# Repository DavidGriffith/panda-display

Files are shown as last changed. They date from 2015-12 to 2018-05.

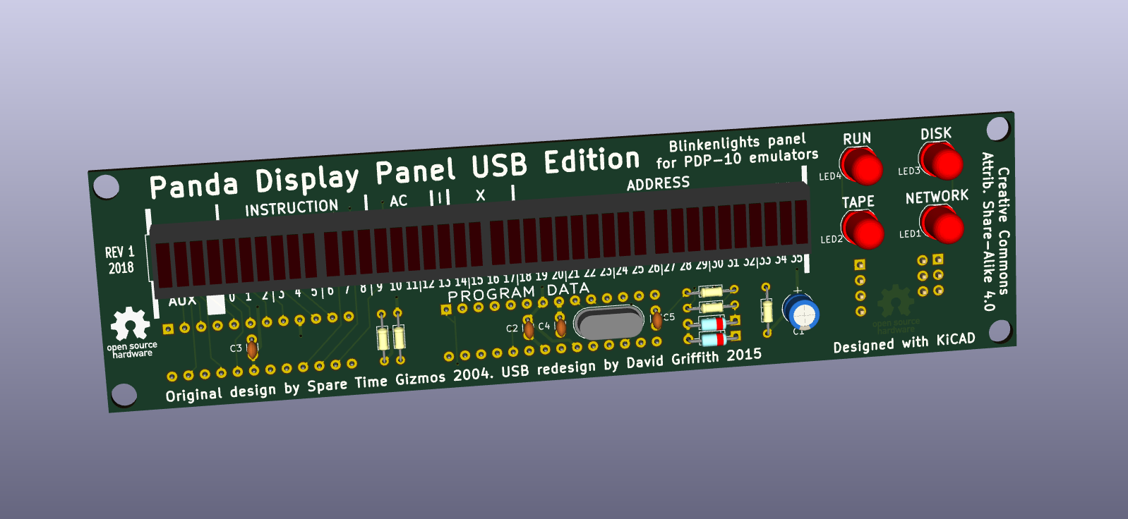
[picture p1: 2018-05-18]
panda-front.png

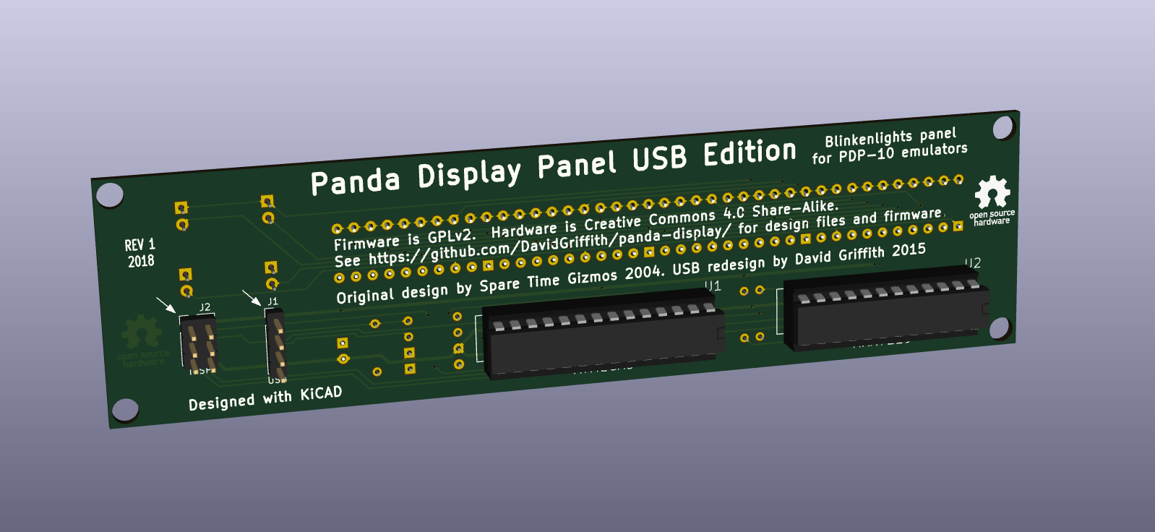
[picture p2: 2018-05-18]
panda-back.png

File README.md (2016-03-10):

Panda Display Panel
===================

---

The Panda Display Panel is a hardware peripheral for use with the klh10 
pdp-10 emulator.  It was originally presented by Spare Time Gizmos.  
This one replaces the parallel port interface with a USB interface.

The original Panda Display Panel page is at 
http://www.sparetimegizmos.com/Hardware/Panda.htm

**Bill of Materials**

|Connectors| |
|:---|---|
|J1| 1 x 4 0.1" header strip|
|J2| 2 x 3 0.1" header strip|
|U1| 28-pin narrow DIP socket|
|U2| 24-pin narrow DIP socket|

|Semiconductors| |
|:---|---|
|U1|		ATmega8 microcontroller -- 28-pin narrow DIP|
|U2|		Maxim MAX7219 matrix digit display driver -- 24-pin narrow DIP|
|D1,D2|		1N747 3.6V zener diodes|
|BAR1-BAR4|	10 segment LED bar display -- Lite-On LTA-1000HR|
|LED1-LED4|	Standard brightness red LED 5mm -- Kingbright WP1503ID|

|Crystals| |
|:---|---|
|Y1|		16MHz quartz crystal -- HC49/US low profile|

|Resistors| |
|:---|---|
|R1|		2.2K 0.25W 5%|
|R2|		4.7K 0.25W 5%|
|R3,R4|		68 0.25W 5%|
|R5|		10K  0.25W 5%|

|Capacitors| |
|:---|---|
|C1|		10uF 25V electrolytic or tantalum|
|C2,C3|		0.1uF ceramic monolithic|
|C4,C5|		22pF ceramic monolithic|

**Assembly Notes**

Pay careful attention to the fact that the chips are mounted on the rear 
of the board and most of the passives are on the front.

1.  Mount the passive components first.  Make sure the leads are trimmed 
    so they won't interfere with the chip sockets.  The polarized 
    capacitor should be laid down on its side.
2.  Wash flux residue off the rear.  The chip sockets will make this 
    more difficult later.
3.  Mount the chip sockets and the header strips on the rear
4.  Mount the LED bars and the discrete LEDs on the front.

The discrete LEDs may be pressed up against the board unless you decide 
to mount the LED bars in sockets.  If you want to do that, first mount 
sockets and install the LED bars in the sockets.  Then insert a discrete 
LED and turn the Panda Display over such that the LED bars lie flat upon 
the table.  Let the discrete LED fall against the table.  Once you're 
satisfied that the discrete LED is level with the LED bars, solder the 
discrete LED in place.  Repeat for the other discrete LEDs.

To build and install the firmware, you must have the AVR-GCC development 
environment including compiler, binutilities, and libc 
(http://www.nongnu.org/avr-libc/) and AVRDUDE
(http://www.nongnu.org/avrdude/) installed.  Most if not all current 
distributions of Linux and BSD include packages for installing these.  
You will also need an AVR programming device supported by AVRDUDE.  A 
USBtinyISP (https://www.adafruit.com/products/46) is commonly-available, 
reliable, and inexpensive.

It's a good idea to add your programmer to your system's udev rules.  
For the USBtinyISP, see https://learn.adafruit.com/usbtinyisp/avrdude

**Mounting and Use**

The Panda Display is intended to be mounted in a 5.25" external drive 
bay behind a knockout panel.  It's up to you to make this as simply or 
elaborately as you desire.  An overlay may be applied over the top to 
dress it up.

This edition of the Panda Display is powered and driven through a USB 
port.  There are two ways of going about the cabling.  If you have a 
spare USB header on your computer's motherboard, you'll need to make up 
a four-conductor cable terminated at both ends with a 1x4 0.1" female 
header socket.

If you have a regular Type-A socket inside your computer, take an 
ordinary USB cable, cut off the Type-B end, trim the jacket, and crimp 
the conductors to a 1x4 0.1" female header socket.

Finally, to make any meaningful use of the Panda Display, you will need 
a PDP-10 emulator which has been patched to make use of it.  Since 
Kenneth L. Harrenstien's klh10 pdp-10 emulator was patched by Mark 
Crispin to use the original Panda Display, I chose to modify that to use 
this new Panda Display.  Get it here: 
https://github.com/DavidGriffith/klh10.

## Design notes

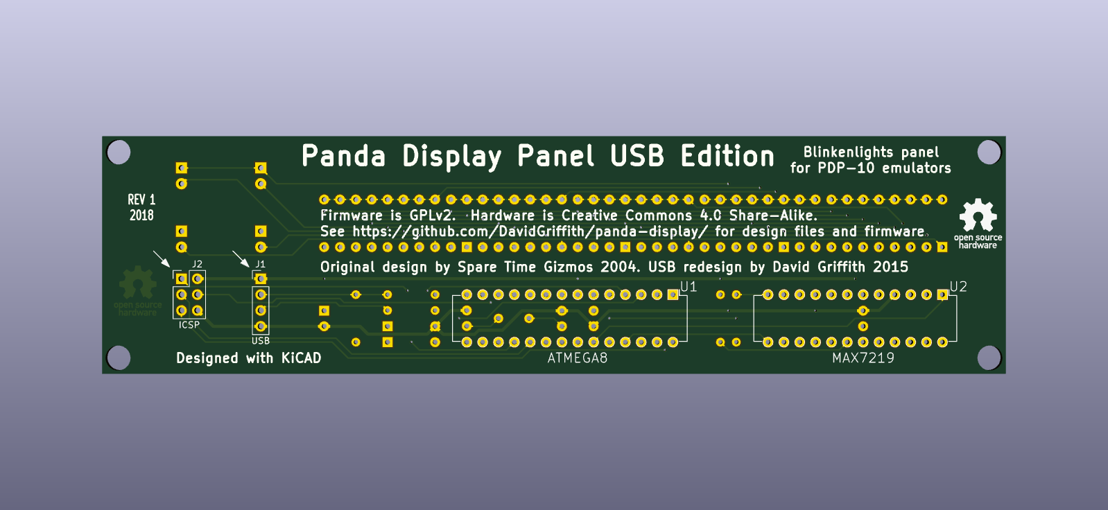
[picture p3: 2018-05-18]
panda-back-bare.png

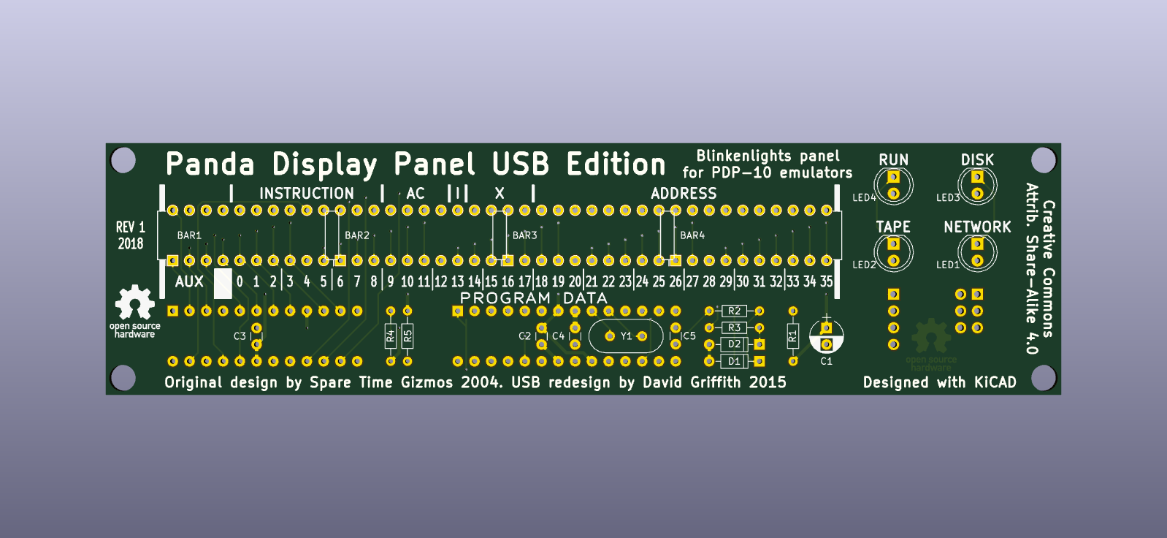
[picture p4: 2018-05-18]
panda-front-bare.png

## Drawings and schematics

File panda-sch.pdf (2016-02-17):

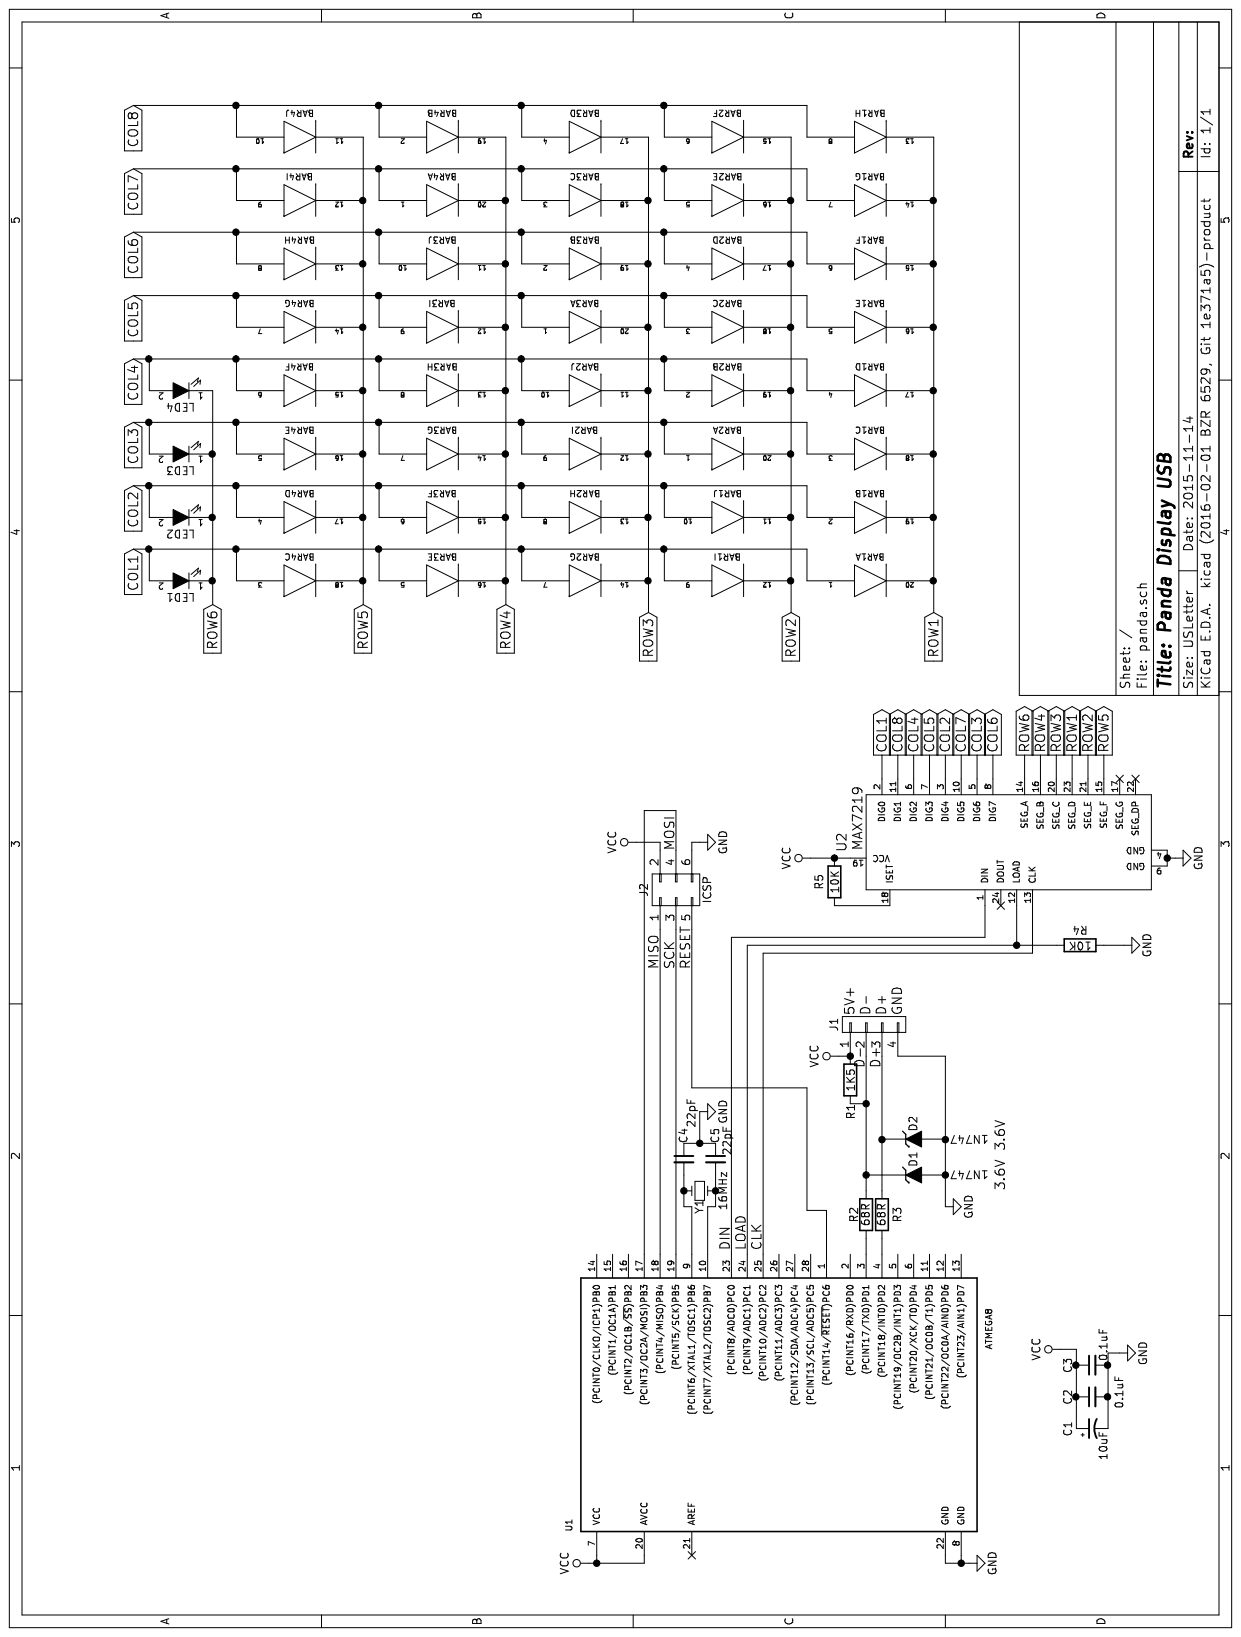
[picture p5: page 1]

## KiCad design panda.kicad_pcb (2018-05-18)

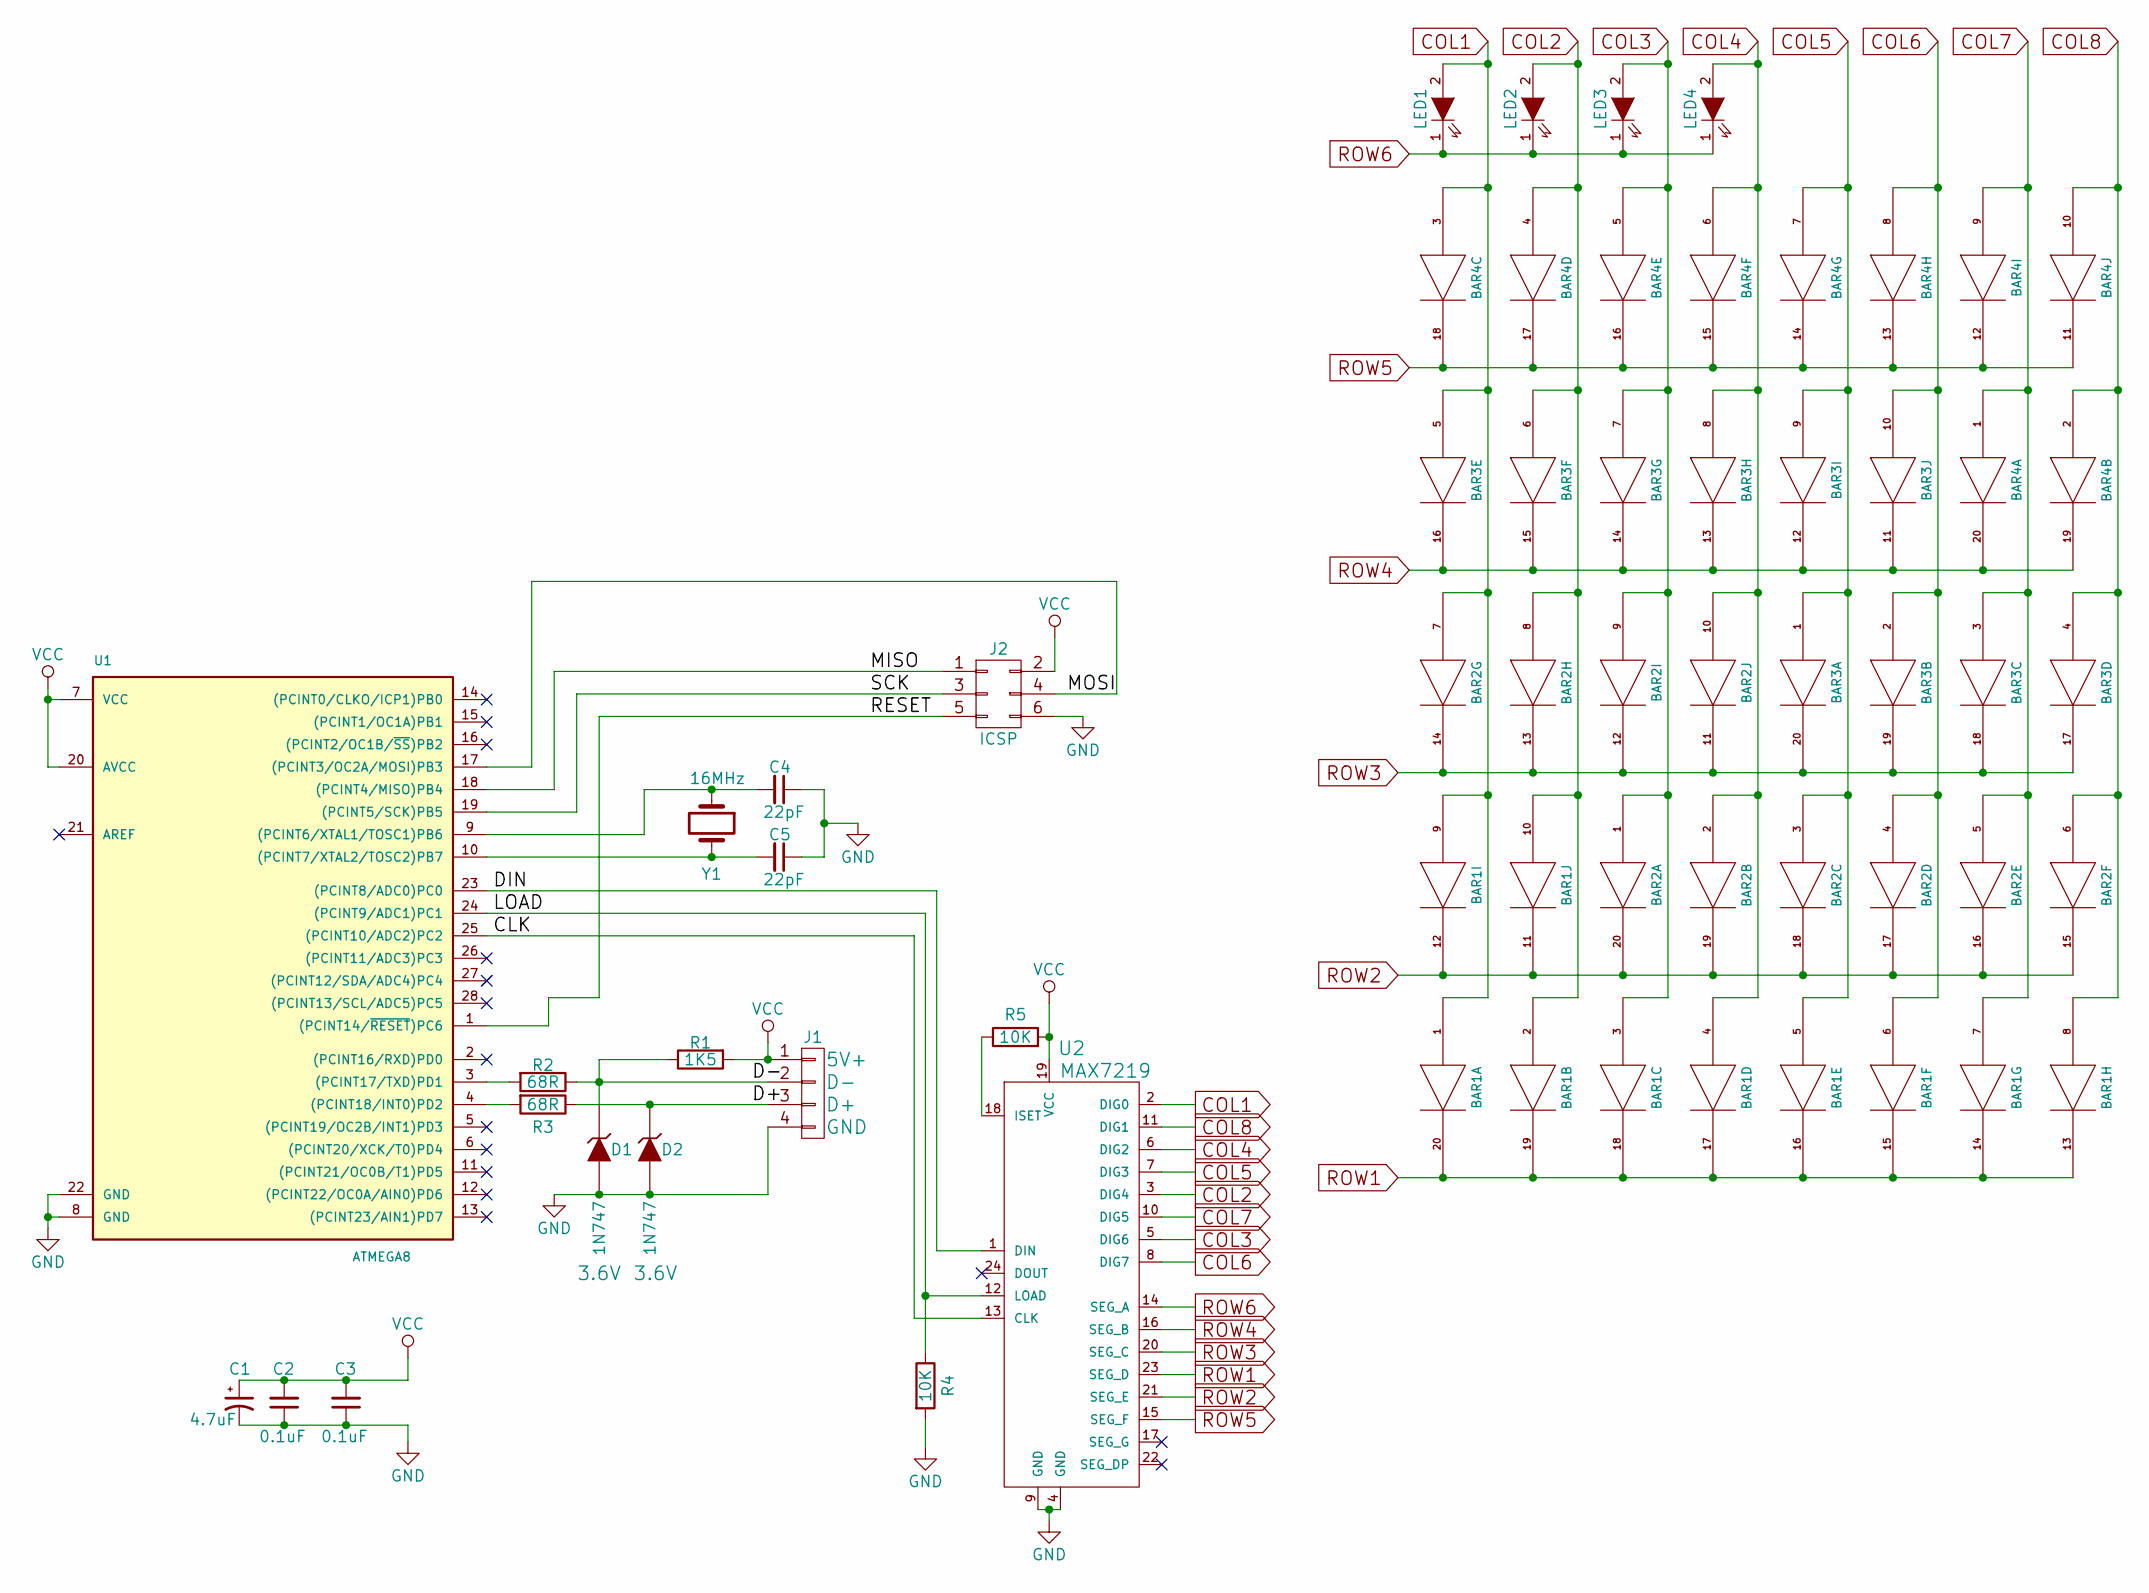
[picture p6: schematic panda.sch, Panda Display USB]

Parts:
BAR1, BAR2, BAR3, BAR4: DOT-BAR; DIP-20_W7.62mm
C1: 4.7uF; CP_Radial_D5.0mm_P2.50mm
C2, C3: 0.1uF; C_Disc_D3.0mm_W1.6mm_P2.50mm
C4, C5: 22pF; C_Disc_D3.0mm_W1.6mm_P2.50mm
D1, D2: 1N747; D_DO-35_SOD27_P7.62mm_Horizontal; Voltage 3.6V
J1: USB; Pin_Header_Straight_1x04_Pitch2.54mm
J2: ICSP; Pin_Header_Straight_2x03_Pitch2.54mm
LED1, LED2, LED3, LED4: LED; LED_D5.0mm
R1: 1K5; R_Axial_DIN0204_L3.6mm_D1.6mm_P7.62mm_Horizontal
R2, R3: 68R; R_Axial_DIN0204_L3.6mm_D1.6mm_P7.62mm_Horizontal
R4, R5: 10K; R_Axial_DIN0204_L3.6mm_D1.6mm_P7.62mm_Horizontal
U1: ATMEGA8; DIP-28_W7.62mm
U2: MAX7219; DIP-24_W7.62mm
Y1: 16MHz; Crystal_HC49-U_Vertical

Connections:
/CLK: U1.25 ((PCINT10/ADC2)PC2), U2.13 (CLK)
/D+: D2.1 (K), J1.3, R3.1
/D-: D1.1 (K), J1.2, R1.1, R2.1
/DIN: U1.23 ((PCINT8/ADC0)PC0), U2.1 (DIN)
/LOAD: R4.1, U1.24 ((PCINT9/ADC1)PC1), U2.12 (LOAD)
/MISO: J2.1, U1.18 ((PCINT4/MISO)PB4)
/MOSI: J2.4, U1.17 ((PCINT3/OC2A/MOSI)PB3)
/RESET: J2.5, U1.1 ((PCINT14/~RESET~)PC6)
/SCK: J2.3, U1.19 ((PCINT5/SCK)PB5)
COL1: BAR1.1 (A), BAR1.9 (A), BAR2.7 (A), BAR3.5 (A), BAR4.3 (A), LED1.2 (A), U2.2 (DIG0)
COL2: BAR1.2 (A), BAR1.10 (A), BAR2.8 (A), BAR3.6 (A), BAR4.4 (A), LED2.2 (A), U2.3 (DIG4)
COL3: BAR1.3 (A), BAR2.1 (A), BAR2.9 (A), BAR3.7 (A), BAR4.5 (A), LED3.2 (A), U2.5 (DIG6)
COL4: BAR1.4 (A), BAR2.2 (A), BAR2.10 (A), BAR3.8 (A), BAR4.6 (A), LED4.2 (A), U2.6 (DIG2)
COL5: BAR1.5 (A), BAR2.3 (A), BAR3.1 (A), BAR3.9 (A), BAR4.7 (A), U2.7 (DIG3)
COL6: BAR1.6 (A), BAR2.4 (A), BAR3.2 (A), BAR3.10 (A), BAR4.8 (A), U2.8 (DIG7)
COL7: BAR1.7 (A), BAR2.5 (A), BAR3.3 (A), BAR4.1 (A), BAR4.9 (A), U2.10 (DIG5)
COL8: BAR1.8 (A), BAR2.6 (A), BAR3.4 (A), BAR4.2 (A), BAR4.10 (A), U2.11 (DIG1)
GND: C1.2, C2.1, C3.1, C4.1, C5.1, D1.2 (A), D2.2 (A), J1.4, J2.6, R4.2, U1.8 (GND), U1.22 (GND), U2.4 (GND), U2.9 (GND)
unnamed: C4.2, U1.9 ((PCINT6/XTAL1/TOSC1)PB6), Y1.1
unnamed: C5.2, U1.10 ((PCINT7/XTAL2/TOSC2)PB7), Y1.2
unnamed: R2.2, U1.3 ((PCINT17/TXD)PD1)
unnamed: R3.2, U1.4 ((PCINT18/INT0)PD2)
unnamed: R5.1, U2.18 (ISET)
ROW1: BAR1.13 (K), BAR1.14 (K), BAR1.15 (K), BAR1.16 (K), BAR1.17 (K), BAR1.18 (K), BAR1.19 (K), BAR1.20 (K), U2.23 (SEG_D)
ROW2: BAR1.11 (K), BAR1.12 (K), BAR2.15 (K), BAR2.16 (K), BAR2.17 (K), BAR2.18 (K), BAR2.19 (K), BAR2.20 (K), U2.21 (SEG_E)
ROW3: BAR2.11 (K), BAR2.12 (K), BAR2.13 (K), BAR2.14 (K), BAR3.17 (K), BAR3.18 (K), BAR3.19 (K), BAR3.20 (K), U2.20 (SEG_C)
ROW4: BAR3.11 (K), BAR3.12 (K), BAR3.13 (K), BAR3.14 (K), BAR3.15 (K), BAR3.16 (K), BAR4.19 (K), BAR4.20 (K), U2.16 (SEG_B)
ROW5: BAR4.11 (K), BAR4.12 (K), BAR4.13 (K), BAR4.14 (K), BAR4.15 (K), BAR4.16 (K), BAR4.17 (K), BAR4.18 (K), U2.15 (SEG_F)
ROW6: LED1.1 (K), LED2.1 (K), LED3.1 (K), LED4.1 (K), U2.14 (SEG_A)
VCC: C1.1, C2.2, C3.2, J1.1, J2.2, R1.2, R5.2, U1.7 (VCC), U1.20 (AVCC), U2.19 (VCC)

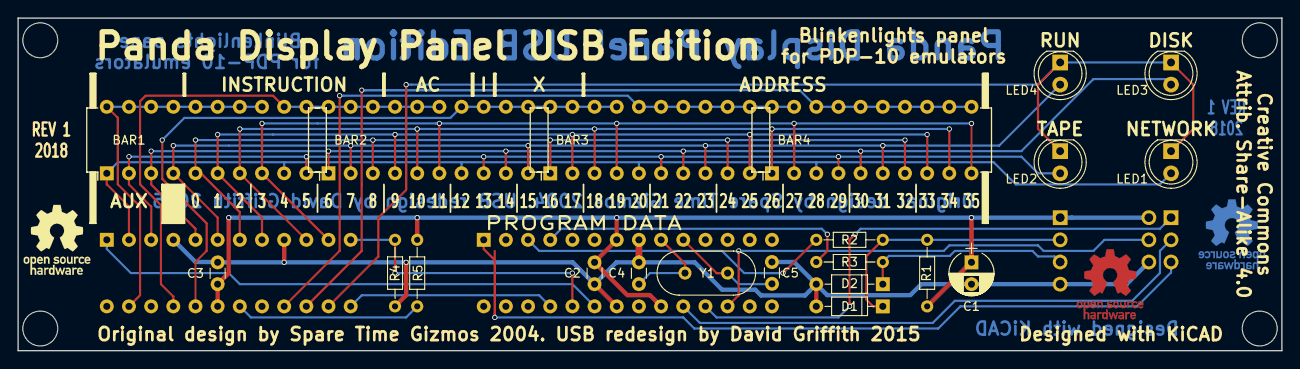
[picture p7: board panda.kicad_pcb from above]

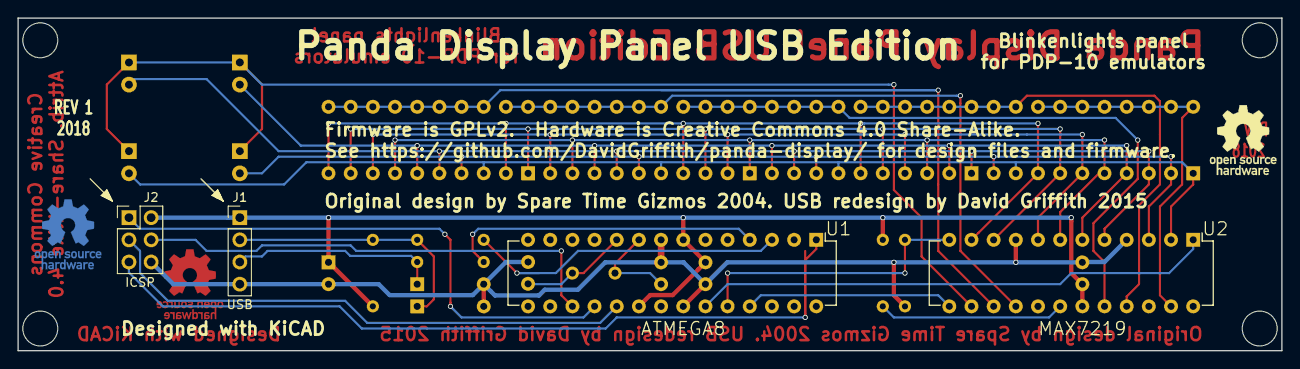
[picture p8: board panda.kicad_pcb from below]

Board: 2 copper layers, 144.8 x 38.1 mm, 25 parts (4 on the bottom side), 30 nets.

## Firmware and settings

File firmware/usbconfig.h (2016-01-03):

/* Name: usbconfig.h
 * Project: V-USB, virtual USB port for Atmel's(r) AVR(r) microcontrollers
 * Author: Christian Starkjohann
 * Creation Date: 2005-04-01
 * Tabsize: 4
 * Copyright: (c) 2005 by OBJECTIVE DEVELOPMENT Software GmbH
 * License: GNU GPL v2 (see License.txt), GNU GPL v3 or proprietary (CommercialLicense.txt)
 */

#ifndef __usbconfig_h_included__
#define __usbconfig_h_included__

/*
General Description:
This file is an example configuration (with inline documentation) for the USB
driver. It configures V-USB for USB D+ connected to Port D bit 2 (which is
also hardware interrupt 0 on many devices) and USB D- to Port D bit 4. You may
wire the lines to any other port, as long as D+ is also wired to INT0 (or any
other hardware interrupt, as long as it is the highest level interrupt, see
section at the end of this file).
*/

/* ---------------------------- Hardware Config ---------------------------- */

#define USB_CFG_IOPORTNAME      D
/* This is the port where the USB bus is connected. When you configure it to
 * "B", the registers PORTB, PINB and DDRB will be used.
 */
#define USB_CFG_DMINUS_BIT      1
/* This is the bit number in USB_CFG_IOPORT where the USB D- line is connected.
 * This may be any bit in the port.
 */
#define USB_CFG_DPLUS_BIT       2
/* This is the bit number in USB_CFG_IOPORT where the USB D+ line is connected.
 * This may be any bit in the port. Please note that D+ must also be connected
 * to interrupt pin INT0! [You can also use other interrupts, see section
 * "Optional MCU Description" below, or you can connect D- to the interrupt, as
 * it is required if you use the USB_COUNT_SOF feature. If you use D- for the
 * interrupt, the USB interrupt will also be triggered at Start-Of-Frame
 * markers every millisecond.]
 */
#define USB_CFG_CLOCK_KHZ       (F_CPU/1000)
/* Clock rate of the AVR in kHz. Legal values are 12000, 12800, 15000, 16000,
 * 16500, 18000 and 20000. The 12.8 MHz and 16.5 MHz versions of the code
 * require no crystal, they tolerate +/- 1% deviation from the nominal
 * frequency. All other rates require a precision of 2000 ppm and thus a
 * crystal!
 * Since F_CPU should be defined to your actual clock rate anyway, you should
 * not need to modify this setting.
 */
#define USB_CFG_CHECK_CRC       0
/* Define this to 1 if you want that the driver checks integrity of incoming
 * data packets (CRC checks). CRC checks cost quite a bit of code size and are
 * currently only available for 18 MHz crystal clock. You must choose
 * USB_CFG_CLOCK_KHZ = 18000 if you enable this option.
 */

/* ----------------------- Optional Hardware Config ------------------------ */

/* #define USB_CFG_PULLUP_IOPORTNAME   D */
/* If you connect the 1.5k pullup resistor from D- to a port pin instead of
 * V+, you can connect and disconnect the device from firmware by calling
 * the macros usbDeviceConnect() and usbDeviceDisconnect() (see usbdrv.h).
 * This constant defines the port on which the pullup resistor is connected.
 */
/* #define USB_CFG_PULLUP_BIT          4 */
/* This constant defines the bit number in USB_CFG_PULLUP_IOPORT (defined
 * above) where the 1.5k pullup resistor is connected. See description
 * above for details.
 */

/* --------------------------- Functional Range ---------------------------- */
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

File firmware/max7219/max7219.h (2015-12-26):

/*
max7219 lib 0x01

copyright (c) Davide Gironi, 2013

Released under GPLv3.
Please refer to LICENSE file for licensing information.
*/


#ifndef MAX7219_H_
#define MAX7219_H_

#include <avr/io.h>


//setup ports
/*
#define MAX7219_DINDDR DDRD
#define MAX7219_DINPORT PORTD
#define MAX7219_DININPUT PD2
#define MAX7219_CLKDDR DDRD
#define MAX7219_CLKPORT PORTD
#define MAX7219_CLKINPUT PD3
#define MAX7219_LOADDDR DDRD
#define MAX7219_LOADPORT PORTD
#define MAX7219_LOADINPUT PD4
*/

#define MAX7219_DINDDR DDRC
#define MAX7219_DINPORT PORTC
#define MAX7219_DININPUT PC0

#define MAX7219_CLKDDR DDRC
#define MAX7219_CLKPORT PORTC
#define MAX7219_CLKINPUT PC2

#define MAX7219_LOADDDR DDRC
#define MAX7219_LOADPORT PORTC
#define MAX7219_LOADINPUT PC1

//setup number of chip attached to the board
//#define MAX7219_ICNUMBER 2
#define MAX7219_ICNUMBER 1

//define registers
#define MAX7218_REGNOOP 0x00
#define MAX7218_REGDIGIT0 0x01
#define MAX7218_REGDIGIT1 0x02
#define MAX7218_REGDIGIT2 0x03
#define MAX7218_REGDIGIT3 0x04
#define MAX7218_REGDIGIT4 0x05
#define MAX7218_REGDIGIT5 0x06
#define MAX7218_REGDIGIT6 0x07
#define MAX7218_REGDIGIT7 0x08
#define MAX7218_REGDECODE 0x09
#define MAX7218_REGINTENSITY 0x0A
#define MAX7218_REGSCANLIMIT 0x0B
#define MAX7218_REGSHUTDOWN 0x0C
#define MAX7218_REGTEST 0x0F


//functions
extern void max7219_send(uint8_t icnum, uint8_t reg, uint8_t data);
extern void max7219_shutdown(uint8_t icnum, uint8_t value);
extern void max7219_intensity(uint8_t icnum, uint8_t value);
extern void max7219_test(uint8_t icnum, uint8_t value);
extern void max7219_scanlimit(uint8_t icnum, uint8_t value);
extern void max7219_decode(uint8_t icnum, uint8_t value);
extern void max7219_digit0(uint8_t icnum, uint8_t value);
extern void max7219_digit1(uint8_t icnum, uint8_t value);
extern void max7219_digit2(uint8_t icnum, uint8_t value);
extern void max7219_digit3(uint8_t icnum, uint8_t value);
extern void max7219_digit4(uint8_t icnum, uint8_t value);
extern void max7219_digit5(uint8_t icnum, uint8_t value);
extern void max7219_digit6(uint8_t icnum, uint8_t value);
extern void max7219_digit7(uint8_t icnum, uint8_t value);
extern void max7219_digit(uint8_t icnum, uint8_t digit, uint8_t value);
extern void max7219_init();

#endif

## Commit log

2015-11-19 Initial commit.
    [panda.kicad_pcb, panda.sch]
2015-11-25 Move chips and polarized capacitor to other side. Makes for easier socketing.
    [panda.kicad_pcb, panda.sch]
2015-11-25 Fixed up 3d models.
    [panda.kicad_pcb]
2015-12-02 Add voltage labels to zener diodes.
    [panda.sch]
2015-12-05 Cleanup and wording.
    [panda.kicad_pcb, panda.sch]
2015-12-05 Add BOM and assembly and use notes.
2015-12-05 Enlarge vias and added blurbs.
    [panda.kicad_pcb]
2015-12-05 Minor aesthetic tweak.
    [panda.kicad_pcb]
2015-12-05 Even more tweaks.
    [panda.kicad_pcb]
2015-12-08 Tweak board and update 3d renders.
    [panda.kicad_pcb]
2015-12-26 Slight mods to accomodate firmware.
    [panda.kicad_pcb, panda.sch]
2016-01-03 Moving D- pin around in firmware.
2016-01-03 Adding PDF of schematics for convenient browsing.
2016-01-25 Update tweaks.
    [panda.kicad_pcb, panda.sch]
2016-02-06 Final tweaks.
    [panda.kicad_pcb, panda.sch]
2016-02-06 3d rendering tweaks.
    [panda.kicad_pcb]
2016-02-17 Update PDF schematics.
2016-02-21 Tweak value of polarized cap.
    [panda.sch]
2016-02-21 Shift OSH logo down to avoid hitting the LED3's column trace.
    [panda.kicad_pcb]
2016-02-25 Rework firmware to make more sense on the host end.
    It turns out that the board with a MAX7219 and an 8x8 LED matrix I was
    using for testing has a funky pinout which doesn't match how the Panda
    Display is wired. Pin 1 does not correspond to column 1 and so on. Then
    I discovered that I wired the board such that I need to rotate the
    bitmap 90 degrees clockwise. I could possibly rework the board design
    to save time in the microcontroller. Maybe it's not necessary,
    particularly given the thing is running at 16MHz.
2016-02-26 Rewrote assembly notes.
2018-05-17 Added 3D model from http://smisioto.no-ip.org/elettronica/kicad/kicad-en.htm
2018-05-17 More 3D models from http://smisioto.no-ip.org/elettronica/kicad/kicad-en.htm
    Socketed DIPs.
2018-05-17 Clean up lots of messiness.
    [panda.kicad_pcb, panda.sch]
2018-05-17 Moved around silks. Added helpful legends.
    [panda.kicad_pcb]
2018-05-18 Scoot chips down a bit to make room for nicer looking Program Data legends.
    [panda.kicad_pcb]
2018-05-18 Update 3D board renders.
2018-05-18 Add copper layer to revision marking.
    [panda.kicad_pcb]
2018-05-18 Add legends to descrete LEDs. Fix the disk LED's 3D rendering elevation.
    [panda.kicad_pcb]
2018-05-18 Move around copper layer Open Source Hardware logos.
    [panda.kicad_pcb]
2018-05-18 Update 3D renders and add renders of the bare board.

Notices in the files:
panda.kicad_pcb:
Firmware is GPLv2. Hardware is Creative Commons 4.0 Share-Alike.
